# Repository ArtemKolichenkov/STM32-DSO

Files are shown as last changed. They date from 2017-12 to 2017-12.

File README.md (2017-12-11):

# Digital storage oscilloscope using STM32
NOTE! Work in progress, the code has a lot of bugs and should not be used in production.

This project is based on STM32F429ZI microcontroller. Desktop client is written in Python, PCB layout is done in KiCad.
Code will be updated gradually and I will notify when the stable version is released.

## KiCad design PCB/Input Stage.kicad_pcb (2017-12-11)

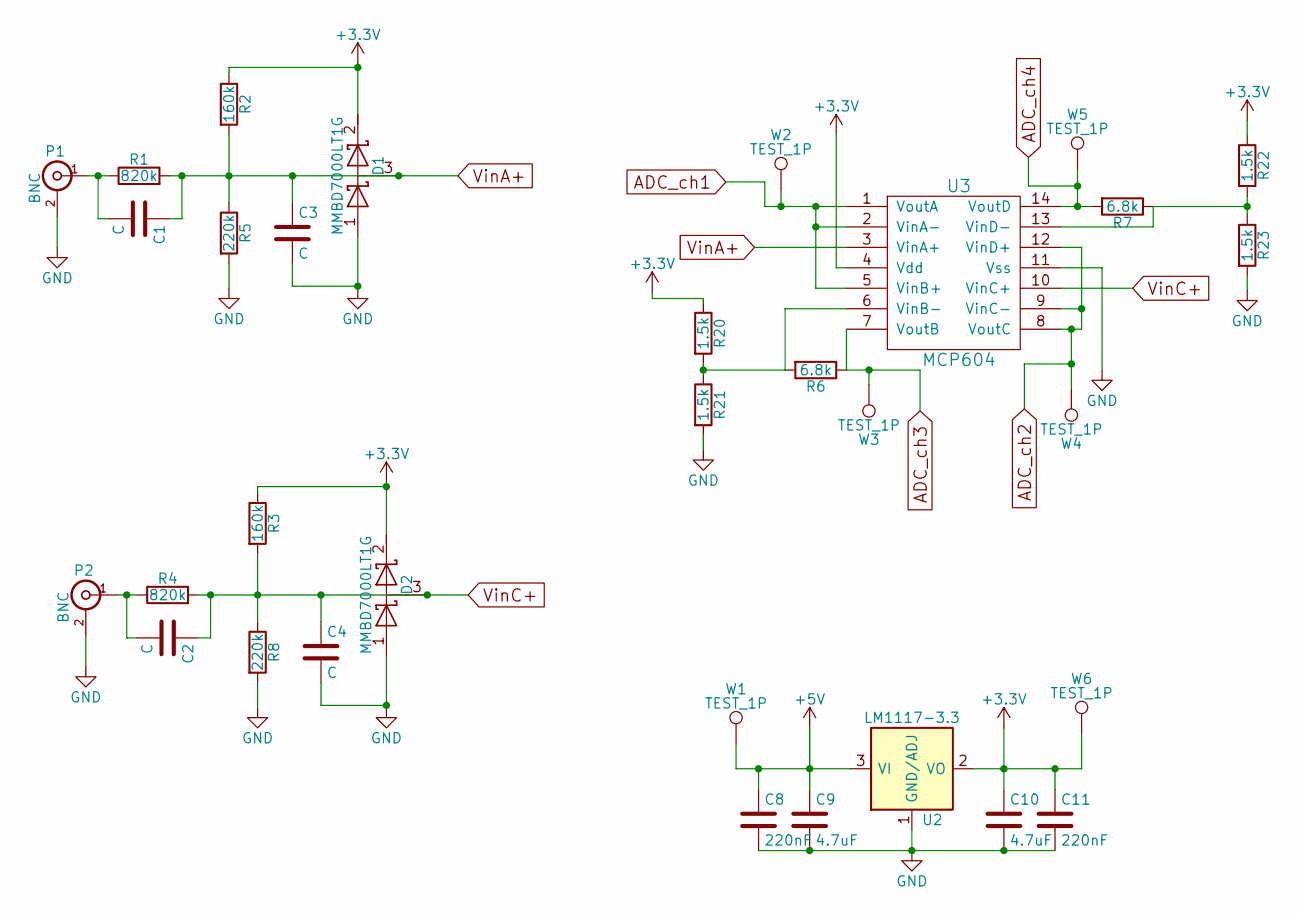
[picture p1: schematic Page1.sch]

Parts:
C1, C2, C3, C4: C; C_0805_HandSoldering
C8, C11: 220nF; C_0805_HandSoldering
C9, C10: 4.7uF; CP_Tantalum_Case-A_EIA-3216-18_Hand
D1, D2: MMBD7000LT1G; SOT-23
P1, P2: BNC; BNC_Socket_TYCO-AMP_LargePads
R1, R4: 820k; R_1206_HandSoldering
R2, R3: 160k; R_1206_HandSoldering
R5, R8: 220k; R_1206_HandSoldering
R6, R7: 6.8k; R_1206_HandSoldering
R20, R21, R22, R23: 1.5k; R_1206_HandSoldering
U2: LM1117-3.3; SOT-223
U3: MCP604; SOIC-14_N
W1, W2, W3, W4, W5, W6: TEST_1P; Measurement_Point_Round-SMD-Pad_Big

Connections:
+5V: C8.1, C9.1, U2.3 (VI), W1.1; also elsewhere on the board
ADC_ch1: U3.1 (VoutA), U3.2 (VinA-), U3.5 (VinB+), W2.1; also elsewhere on the board
ADC_ch2: U3.8 (VoutC), U3.9 (VinC-), U3.12 (VinD+), W4.1; also elsewhere on the board
ADC_ch3: R6.1, U3.7 (VoutB), W3.1; also elsewhere on the board
ADC_ch4: R7.2, U3.14 (VoutD), W5.1; also elsewhere on the board
GND: C3.2, C4.2, C8.2, C9.2, C10.2, C11.2, D1.1 (A), D2.1 (A), P1.2 (Ext), P2.2 (Ext), R5.2, R8.2, R21.2, R23.2, U2.1 (GND/ADJ), U3.11 (Vss); also elsewhere on the board
unnamed: C1.2, P1.1 (In), R1.1
unnamed: C2.2, P2.1 (In), R4.1
unnamed: R6.2, R20.2, R21.1, U3.6 (VinB-)
unnamed: R7.1, R22.2, R23.1, U3.13 (VinD-)
VBAT: C10.1, C11.1, D1.2 (K), D2.2 (K), R2.1, R3.1, R20.1, R22.1, U2.2 (VO), U2.4 (VO), U3.4 (Vdd), W6.1; also elsewhere on the board
VinA+: C1.1, C3.1, D1.3 (common), R1.2, R2.2, R5.1, U3.3 (VinA+)
VinC+: C2.1, C4.1, D2.3 (common), R3.2, R4.2, R8.1, U3.10 (VinC+)

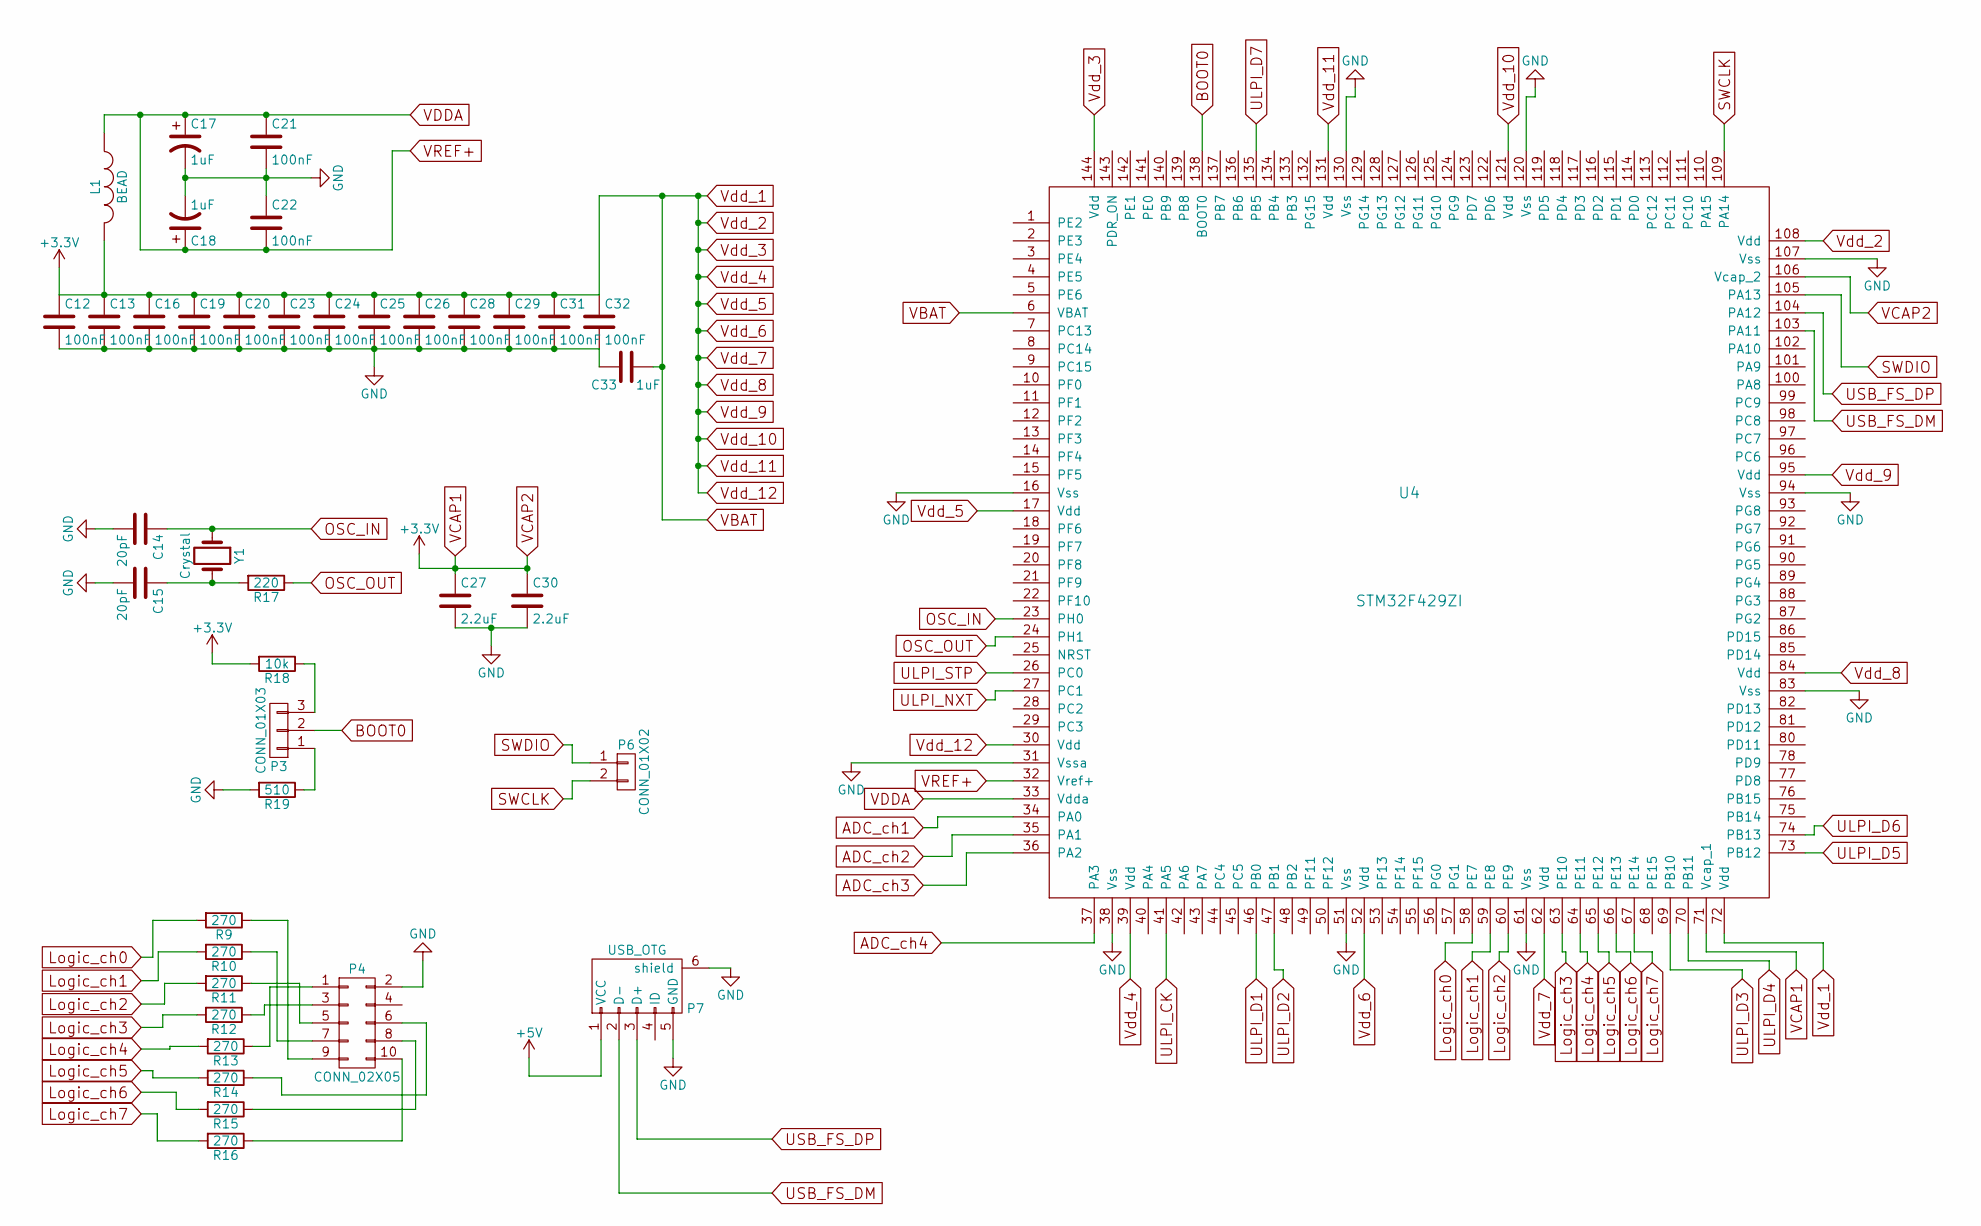
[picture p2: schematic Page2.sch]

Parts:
C12, C13, C16, C19, C20, C21, C22, C23, C24, C25, C26, C28, C29, C31, C32: 100nF; C_0805_HandSoldering
C14, C15: 20pF; C_0805_HandSoldering
C17, C18: 1uF; CP_Tantalum_Case-A_EIA-3216-18_Hand
C27, C30: 2.2uF; C_0805_HandSoldering
C33: 1uF; C_0805_HandSoldering
L1: BEAD; C_1210_HandSoldering
P3: CONN_01X03; Pin_Header_Straight_1x03_Pitch2.54mm
P4: CONN_02X05; IDC_Header_Straight_10pins
P6: CONN_01X02; Pin_Header_Straight_1x02_Pitch2.54mm
P7: USB_OTG; USB_Mini-B
R9, R10, R11, R12, R13, R14, R15, R16: 270; R_1206_HandSoldering
R17: 220; R_1206_HandSoldering
R18: 10k; R_1206_HandSoldering
R19: 510; R_1206_HandSoldering
U4: STM32F429ZI; LQFP-144_20x20mm_Pitch0.5mm
Y1: Crystal; Crystal_SMD_HC49-SD_HandSoldering

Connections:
+5V: P7.1 (VCC); also elsewhere on the board
ADC_ch1: U4.34 (PA0); also elsewhere on the board
ADC_ch2: U4.35 (PA1); also elsewhere on the board
ADC_ch3: U4.36 (PA2); also elsewhere on the board
ADC_ch4: U4.37 (PA3); also elsewhere on the board
BOOT0: P3.2, U4.138 (BOOT0)
GND: C12.2, C13.2, C14.2, C15.2, C16.2, C17.2, C18.2, C19.2, C20.2, C21.2, C22.1, C23.2, C24.2, C25.2, C26.2, C27.2, C28.2, C29.2, C30.2, C31.2, C32.2, C33.2, P4.2, P7.5 (GND), P7.6 (shield), R19.2, U4.16 (Vss), U4.31 (Vssa), U4.38 (Vss), U4.51 (Vss), U4.61 (Vss), U4.83 (Vss), U4.94 (Vss), U4.107 (Vss), U4.120 (Vss), U4.130 (Vss); also elsewhere on the board
Logic_ch0: R9.2, U4.58 (PE7)
Logic_ch1: R10.2, U4.59 (PE8)
Logic_ch2: R11.2, U4.60 (PE9)
Logic_ch3: R12.2, U4.63 (PE10)
Logic_ch4: R13.2, U4.64 (PE11)
Logic_ch5: R14.2, U4.65 (PE12)
Logic_ch6: R15.2, U4.66 (PE13)
Logic_ch7: R16.2, U4.67 (PE14)
unnamed: C15.1, R17.2, Y1.2
unnamed: P3.1, R19.1
unnamed: P3.3, R18.1
unnamed: P4.1, R13.1
unnamed: P4.3, R12.1
unnamed: P4.5, R11.1
unnamed: P4.6, R14.1
unnamed: P4.7, R10.1
unnamed: P4.8, R15.1
unnamed: P4.9, R9.1
unnamed: P4.10, R16.1
OSC_IN: C14.1, U4.23 (PH0), Y1.1
OSC_OUT: R17.1, U4.24 (PH1)
SWCLK: P6.2, U4.109 (PA14)
SWDIO: P6.1, U4.105 (PA13)
ULPI_CK: U4.41 (PA5)
ULPI_D1: U4.46 (PB0)
ULPI_D2: U4.47 (PB1)
ULPI_D3: U4.69 (PB10)
ULPI_D4: U4.70 (PB11)
ULPI_D5: U4.73 (PB12)
ULPI_D6: U4.74 (PB13)
ULPI_D7: U4.135 (PB5)
ULPI_NXT: U4.27 (PC1)
ULPI_STP: U4.26 (PC0)
USB_FS_DM: P7.2 (D-), U4.103 (PA11)
USB_FS_DP: P7.3 (D+), U4.104 (PA12)
VBAT: C12.1, C13.1, C16.1, C19.1, C20.1, C23.1, C24.1, C25.1, C26.1, C27.1, C28.1, C29.1, C30.1, C31.1, C32.1, C33.1, L1.2, R18.2, U4.6 (VBAT), U4.17 (Vdd), U4.30 (Vdd), U4.39 (Vdd), U4.52 (Vdd), U4.62 (Vdd), U4.71 (Vcap_1), U4.72 (Vdd), U4.84 (Vdd), U4.95 (Vdd), U4.106 (Vcap_2), U4.108 (Vdd), U4.121 (Vdd), U4.131 (Vdd), U4.144 (Vdd); also elsewhere on the board
VDDA: C17.1, C18.1, C21.1, C22.2, L1.1, U4.32 (Vref+), U4.33 (Vdda)

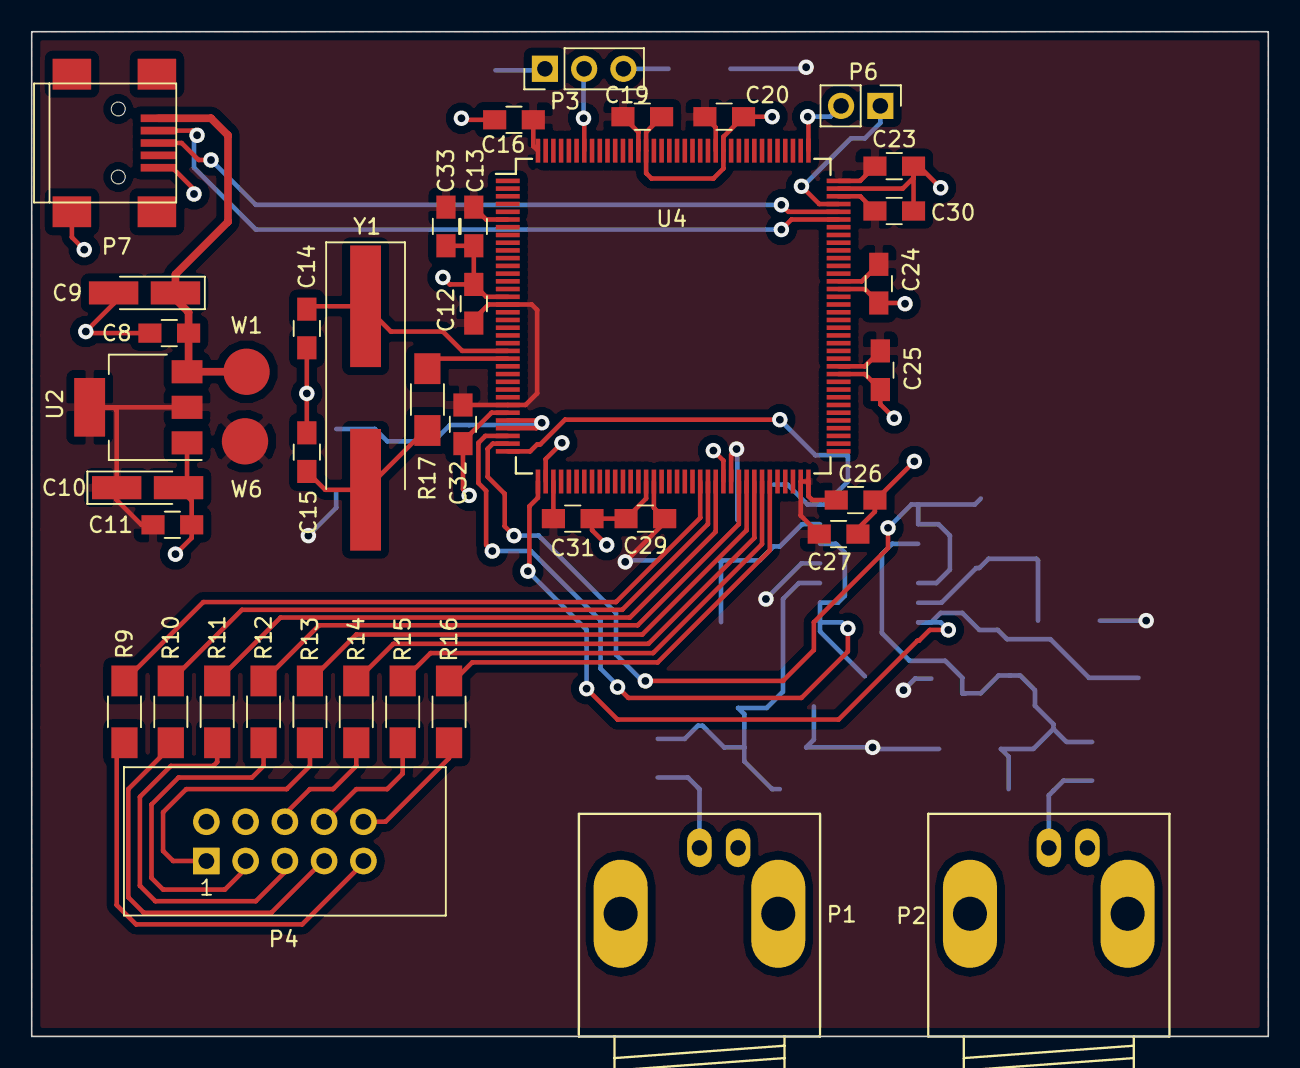
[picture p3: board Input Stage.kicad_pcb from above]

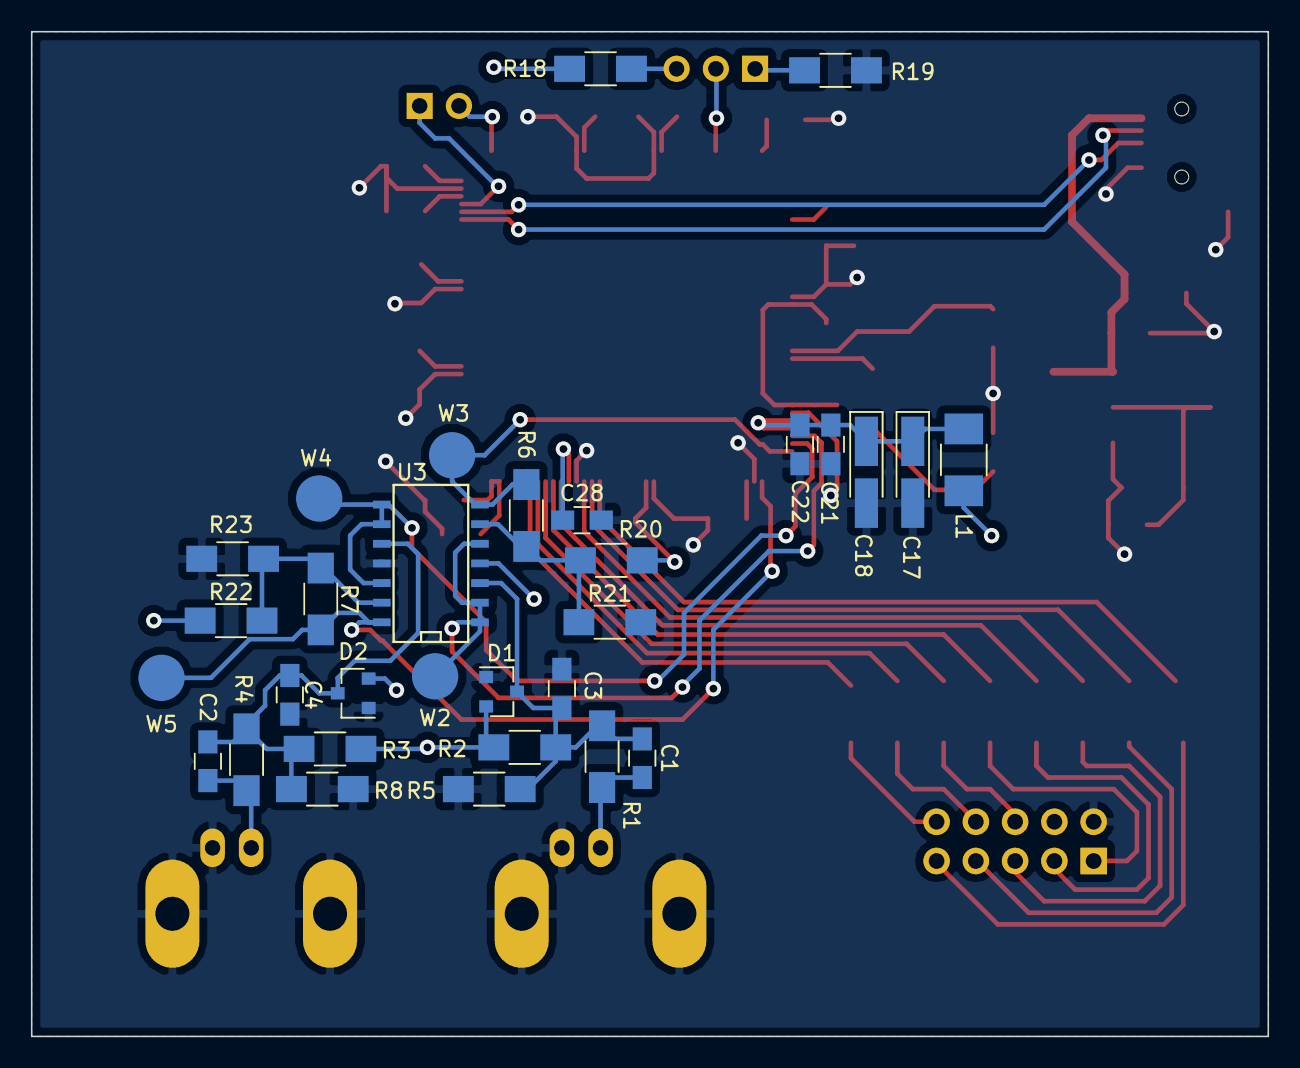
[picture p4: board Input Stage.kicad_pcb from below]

Board: 2 copper layers, 80.0 x 65.0 mm, 72 parts (31 on the bottom side), 40 nets.

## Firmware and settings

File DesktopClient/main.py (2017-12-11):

"""
    Oscilloscope project
"""
from __future__ import division
from PyQt4 import QtGui, QtCore
import design
import sys
import re
import pyqtgraph as pg
import numpy as np
import settings
import serial   
from scipy.signal import blackmanharris
from parabolic import parabolic
import cPickle as pickle

# Initializing configuration object
config = settings.Config()
# Initializing Channel objects for 1st and 2nd channel and setting default parameters
channel_1 = settings.Channel(is_on=True, color='y')
channel_2 = settings.Channel(is_on=False, color='r')

# Initializing Logic objects for logic channels and setting default parameters
logic_channel_0 = settings.LogicChannel(
    is_on=True, color=(255, 255, 255), y_offset=-3.98)
logic_channel_1 = settings.LogicChannel(
    is_on=True, color=(255, 255, 0), y_offset=-3.6)
logic_channel_2 = settings.LogicChannel(
    is_on=True, color=(0, 255, 0), y_offset=-3.22)
logic_channel_3 = settings.LogicChannel(
    is_on=True, color=(0, 0, 255), y_offset=-2.84)
logic_channel_4 = settings.LogicChannel(
    is_on=True, color=(255, 0, 255), y_offset=-2.46)
logic_channel_5 = settings.LogicChannel(
    is_on=True, color=(255, 0, 0), y_offset=-2.08)
logic_channel_6 = settings.LogicChannel(
    is_on=True, color=(0, 255, 255), y_offset=-1.7)
logic_channel_7 = settings.LogicChannel(
    is_on=True, color=(255, 165, 0), y_offset=-1.32)

# Putting logic channels into a list for better code management
logic_channels = [logic_channel_0, logic_channel_1, logic_channel_2, logic_channel_3,
                  logic_channel_4, logic_channel_5, logic_channel_6, logic_channel_7]


def freq_from_fft(channel, fs):
    """
    Estimate frequency from peak of FFT.

    Parameters
    ----------
    channel : Channel object
        Channel to be processed
    fs : int
        Sampling rate

    """
    # Compute Fourier transform of windowed signal
    windowed = channel.signal * blackmanharris(len(channel.signal))
    f = np.fft.rfft(windowed)
    channel.fft_y = np.abs(f)  # amplitude spectrum
    channel.fft_x = np.fft.rfftfreq(channel.signal.size, 1 / fs)
    # Find the peak and interpolate to get a more accurate peak
    i = np.argmax(abs(f))
    true_i = parabolic(np.log(abs(f)), i)[0]

    # Convert to equivalent frequency
    return fs * true_i / len(windowed)


""" Oscilloscope screen related functions are below """


def show_fft_dialog():
    """
    Shows dialog box for FFT and sets curve inside of it.
    """
    fft_dialog = FFTDialog()
    fft_curve = fft_dialog.fft_plot.getPlotItem()
    vb = fft_curve.vb
    fft_curve.plot(channel_1.fft_x[:505], channel_1.fft_y[:505] / 10, pen='w')
    vLine = pg.InfiniteLine(angle=90, movable=False)
    hLine = pg.InfiniteLine(angle=0, movable=False)
    fft_curve.addItem(vLine, ignoreBounds=True)
    fft_curve.addItem(hLine, ignoreBounds=True)
    bottom_axis = fft_curve.getAxis('bottom')
    bottom_axis.setTicks([
        [(1000, '1 kHz'), (50000, '50 kHz'), (100000, '100 kHz'), (200000, '200 kHz'),
         (300000, '300 kHz'), (400000, '400 kHz'), (500000, '500 kHz'), (600000, '600 kHz'),
         (700000, '700 kHz'), (800000, '800 kHz'), (900000, '900 kHz'), (1000000, '1 MHZ')
         ],
        []])
    vb.setLimits(yMin=-20, yMax=400)
    vb.setLimits(xMin=-20000, xMax=1070000)
    label = fft_dialog.freq_label

    def mouseMoved(evt):
        pos = evt[0]  # using signal proxy turns original arguments into a tuple
        if fft_curve.sceneBoundingRect().contains(pos):
            mousePoint = vb.mapSceneToView(pos)
            frequency = int(mousePoint.x())
            if frequency > 1000000:
                frequency = frequency / 1000000
                label.setText("f=%.3F MHz" % frequency)
            elif frequency > 10000:
                frequency = frequency / 1000
                label.setText("f=%.3F kHz" % frequency)
            else:
                label.setText("f=%.3F Hz" % frequency)
            vLine.setPos(mousePoint.x())
            hLine.setPos(mousePoint.y())
    proxy = pg.SignalProxy(fft_curve.scene().sigMouseMoved, rateLimit=60, slot=mouseMoved)
    fft_dialog.exec_()


def plot_fft():
    fft_curve = form.the_plot.plot(pen='w')
    fft_curve.setPos(0, -3.9)
    fft_curve.setData(np.array(range(0, len(channel_1.fft_x)))
                      * (1000 / 1800), channel_1.fft_y / 350)


def acquire_signal(channel):
    """
    Captures data for corresponding channel and makes simple measurements.

    Parameters
    ----------
    channel : Channel object
        Channel where data will be saved.
    """
    def make_measurements(channel, sample_rate):
        channel.max_v = channel.signal.max()
        channel.rms = np.sqrt(np.mean(channel.signal ** 2))
        channel.ptp = np.ptp(channel.signal)
        channel.freq = freq_from_fft(channel, sample_rate)

    if config.original_timescale['value'] <= 0.00005:
        sample_rate = settings.SAMPLE_RATES[0.00005]
    else:
        sample_rate = settings.SAMPLE_RATES[config.original_timescale['value']]

    stm32 = serial.Serial('COM3', 115200) # Baud rate does not matter here since it is not real com port but USB
    stm32.close()
    stm32.open()
    signal_array = np.zeros(7200)
    incoming_data = stm32.read(size=7200)
    for i, x in enumerate(incoming_data):
        # converting 8bit values back to voltages (assuming stable 3.3v supply)
        signal_array[i] = ord(x) * 0.012890625 - 1.65
    
    channel.signal = signal_array

    make_measurements(channel, sample_rate)


def acquire_logic():
    """
    Acquires logic channels data.
    """
    for channel in logic_channels:
        if channel.is_on:
            stm32 = serial.Serial('COM3', 115200) # Baud rate does not matter here since it is not real com port but USB
            stm32.close()
            stm32.open()
            signal_array = np.zeros(1800)
            incoming_data = stm32.read(size=1800)
            for i, x in enumerate(incoming_data):
                signal_array[i] = ord(x)
            channel.signal = signal_array


def plot_logic():
    """
    Plots logic channels onto display.
    """
    def plot_logic_channel(channel):
        channel.curve = form.the_plot.plot(pen=channel.color)
        if config.original_timescale['value'] < 0.00005:
            channel.curve.setPos(
                -((1000 * (0.00005 / config.original_timescale['value']) / 2) - 500), channel.y_offset)
            channel.curve.setData(np.array(range(0, len(channel.signal)))
                                  * (1000 / (config.sample_points / (0.00005 / config.original_timescale['value']))), channel.signal / 4)
        else:
            channel.curve.setPos(
                0, channel.y_offset)
            channel.curve.setData(np.array(range(0, len(channel.signal)))
                                  * (1000 / config.sample_points), channel.signal / 4)
        channel.original_curve = channel.curve.getData()[0]

    for channel in logic_channels:
        if channel.is_on:
            plot_logic_channel(channel)


def update_screen():
    '''
    Updates the oscilloscope screen with new data.
    '''

    def plot_channel(channel):
        channel.curve = form.the_plot.plot(pen=channel.color)
        if config.original_timescale['value'] < 0.00005:
            channel.curve.setPos(
                -((1000 * (0.00005 / config.original_timescale['value']) / 2) - 500), (config.vertical_bounds[1] / 400) * form.vpos_one_slider.value())
            channel.curve.setData(np.array(range(0, len(channel.signal)))
                                  * (1000 / (config.sample_points / (0.00005 / config.original_timescale['value']))), channel.signal)
        else:
            channel.curve.setPos(
                0, (config.vertical_bounds[1] / 400) * form.vpos_one_slider.value())
            channel.curve.setData(np.array(range(0, len(channel.signal)))
                                  * (1000 / config.sample_points), channel.signal)
        channel.original_curve = channel.curve.getData()[0]

    stm32 = serial.Serial('COM3', 115200) # Baud rate does not matter here since it is not real com port but USB
    stm32.close()
    stm32.open()

    if channel_1.is_on and channel_2.is_on:
        stm32.write(b'110')
        acquire_signal(channel_1)
        acquire_signal(channel_2)
        plot_channel(channel_1)
        plot_channel(channel_2)
        vertical_position_changed(channel_1, form.vpos_one_slider, form.vpos_one_value_label)
        vertical_position_changed(channel_2, form.vpos_two_slider, form.vpos_two_value_label)
    elif channel_1.is_on:
        stm32.write(b'100')
        acquire_signal(channel_1)
        plot_channel(channel_1)
        update_measurements()
        vertical_position_changed(channel_1, form.vpos_one_slider, form.vpos_one_value_label)
    else:
        stm32.write(b'010')
        acquire_signal(channel_2)
        plot_channel(channel_2)
        vertical_position_changed(channel_2, form.vpos_two_slider, form.vpos_two_value_label)

    if config.logic_on:
        stm32.write(b'001')
        acquire_logic()
        plot_logic()


def move_horizontal(self):
    '''
    Moves the oscilloscope screen when interacting with horizontal scrollbar.
    '''
    form.the_plot.setXRange(0 + self * 100, 1000 + self * 100, padding=0)


def logic_onoff(logic):
    """
    Turns on logic channels and changes display accordingly.

    Parameters
    ----------
    logic : boolean
        State of logic channels (on/off). Set automatically from GUI event.
    """
    config.logic_on = logic
    if not logic:
        clear_logic_screen()
        form.logic_button.setText("Logic OFF")
    if logic:
        plot_logic()
        form.logic_button.setText("Logic ON")
    check_if_all_channels_off()


def clear_logic_screen():
    """
    Removes logic channels curves from the display.
    """
    for channel in logic_channels:
        form.the_plot.removeItem(channel.curve)


def logic_channel_onoff(checkbox, channel):
    """
    Disables/Enables logic channel.
    Parameters
    ----------
    checkbox : QCheckBox object
        The checkbox that was changed
    channel : LogicChannel object
        LogicChannel instance for corresponding channel

    """
    channel.is_on = checkbox.isChecked()


""" Buttons events for Functions menu are below """


def single():
    '''
    Takes a single snapshot of a signal.
    The length of snapshot is the sample window currently used (or several windows if it is less than 1000 points).
    '''

    clear_screen()
    update_screen()


def clear_screen():
    '''
    Clears oscilloscope screen and erases the data stored in Channel.curve.
    '''
    form.the_plot.removeItem(channel_1.curve)
    channel_1.curve = None

    form.the_plot.removeItem(channel_2.curve)
    channel_2.curve = None

    clear_logic_screen()
    for channel in logic_channels:
        channel.curve = None
        channel.signal = np.array([])


""" Channel controll GUI functions are below """


def ch1_on_off(self):
    """
    Turns on channel_1 object and updates GUI.
    Parameters
    ----------
    self : boolean
        ON/OFF state of channel. Set up automatically from GUI event.
    """
    if self:
        channel_1.is_on = True
        update_GUI()
    else:
        channel_1.is_on = False
        update_GUI()

    check_if_all_channels_off()


def ch2_on_off(self):
    """
    Turns on channel_2 object and updates GUI.

    Parameters
    ----------
    self : boolean
        ON/OFF state of channel. Set up automatically from GUI event.
    """
    if self:
        channel_2.is_on = True
        update_GUI()
    else:
        channel_2.is_on = False
        update_GUI()

    check_if_all_channels_off()


def check_if_all_channels_off():
    """
    Checks if all channels turned off and updates GUI accordingly.
    """
    if not channel_1.is_on and not channel_2.is_on and not config.logic_on:
        form.single_button.setEnabled(False)
        form.run_button.setEnabled(False)
    else:
        form.single_button.setEnabled(True)
        form.run_button.setEnabled(True)


def time_resolution_changed(self):
    """
    Zooms in and out when time resolution changed
    """
    def plot_resized_channel(channel, multiplier):
        if config.original_timescale['value'] < 0.00005:
            channel.curve.setPos(-((1000 * (0.00005 /
                                            config.original_timescale['value']) * multiplier / 2) - 500), 0)
        else:
            channel.curve.setPos(500 - ((1000 * multiplier) / 2), 0)
        channel.curve.setData(channel.original_curve * multiplier, channel.curve.getData()[1])

    def plot_resized_logic_channel(channel, multiplier):
        if config.original_timescale['value'] < 0.00005:
            channel.curve.setPos(-((1000 * (0.00005 /
                                            config.original_timescale['value']) * multiplier / 2) - 500), 0)
        else:
            channel.curve.setPos(500 - ((1000 * multiplier) / 2), channel.y_offset)
        channel.curve.setData(channel.original_curve * multiplier, channel.curve.getData()[1])

    config.current_timescale['value'] = form.hscale_select.itemData(
        form.hscale_select.currentIndex()).toPyObject()

    # Displaying the Max Frequency value
    update_GUI()

    # Determining multiplier for zooming in and out at signal
    multiplier = config.original_timescale['value'] / config.current_timescale['value']

    # Initialize the new curve array with zoomed in and out values
    if channel_1.curve and channel_2.curve:
        plot_resized_channel(channel_1, multiplier)
        plot_resized_channel(channel_2, multiplier)
    elif channel_1.curve:
        plot_resized_channel(channel_1, multiplier)
    elif channel_2.curve:
        plot_resized_channel(channel_2, multiplier)
    else:
        pass
    vertical_position_changed(channel_1, form.vpos_one_slider, form.vpos_one_value_label)
    vertical_position_changed(channel_2, form.vpos_two_slider, form.vpos_two_value_label)

    if config.logic_on:
        for channel in logic_channels:
            plot_resized_logic_channel(channel, multiplier)


def voltage_changed(channel, new_scale):
    """
    Zooms in and out when voltage resolution changed

    Parameters
    ----------
    channel : Channel object
        Corresponding channel for which the vertical resolution has changed.
    new_scale : QComboBox object
        Combobox from which the new value is taken
    """
    def plot_resized_channel(multiplier):
        channel.curve.setData(channel.curve.getData()[0], channel.signal * multiplier)

    channel.voltage_scale = int(re.search(r'\d+', str(new_scale.currentText())).group(0))
    is_mv = re.search(r'mV', str(new_scale.currentText()))
    if is_mv:
        voltage_multiplier = 1 / (channel.voltage_scale / 1000)
        channel.voltage_mv = True
    else:
        voltage_multiplier = 1 / channel.voltage_scale
        channel.voltage_mv = False
    if channel.curve:
        plot_resized_channel(voltage_multiplier)
    trigger_position_changed(form.trigger_level_slider.value())


def vertical_position_changed(channel, slider, label):
    """
    Moves signal curve up and down according to slider position.

    Parameters
    ----------
    channel : Channel object
        Corresponding channel for which the vertical position has changed.
    slider : QSlider object
        Slider from which the new value is taken
    label: QLabel object
        Label below the slider (to update text readout)
    """
    if channel.curve:
        channel.curve.setPos(channel.curve.pos()[
            0], (config.vertical_bounds[1] / 400) * slider.value())
    label.setText(
        str((config.vertical_bounds[1] / (config.vertical_bounds[1] * 100)) * slider.value()) + " div")


def vertical_zero(channel_number):
    """
    Centers signal vertically.

    Parameters
    ----------
    channel_number : int
        Channel (number 1 or 2) which needs to be centered vertically.
    """
    if channel_number == 1:
        form.vpos_one_slider.setValue(0)
    else:
        form.vpos_two_slider.setValue(0)


""" Trigger related functions are below """


def holdoff_value_changed(self):
    """
    Changes holdoff value and updates GUI.

    Parameters
    ----------
    self : int
        The time value. Set up automatically from GUI event.
    """
    if config.holdoff_suffix == "ns":
        config.holdoff_time = self
        if config.holdoff_time == 1000:
            config.holdoff_time = 1
            config.holdoff_suffix = "us"
            form.holdoff_spinBox.setSuffix("us")
            form.holdoff_spinBox.setValue(1.0)
    elif config.holdoff_suffix == "us":
        config.holdoff_time = self
        if self < 1:
            config.holdoff_time = 999.9
            config.holdoff_suffix = "ns"
            form.holdoff_spinBox.setValue(999.9)
            form.holdoff_spinBox.setSuffix("ns")
        if config.holdoff_time == 1000.0:
            config.holdoff_time = 1
            config.holdoff_suffix = "ms"
            form.holdoff_spinBox.setSuffix("ms")
            form.holdoff_spinBox.setValue(1.0)
    elif config.holdoff_suffix == "ms":
        config.holdoff_time = self
        if self < 1:
            config.holdoff_time = 999.9
            config.holdoff_suffix = "us"
            form.holdoff_spinBox.setValue(999.9)
            form.holdoff_spinBox.setSuffix("us")


def trigger_show(show):
    """
    Shows/hides trigger line on the display.

    Parameters
    ----------
    show : boolean
        Enable/Disable trigger display. Set up automatically from GUI event.
    """
    if show:
        form.show_button.setText('Hide')
        config.trigger_curve = form.the_plot.plot(
            [8, 10000], [form.trigger_level_slider.value() / 100, form.trigger_level_slider.value() / 100], pen=settings.TRIGGER_PEN,  symbolBrush=(119, 172, 48), symbolPen='w', symbol='t2', symbolSize=14)
    else:
        form.show_button.setText('Show')
        form.the_plot.removeItem(config.trigger_curve)
        config.trigger_curve = None


def toggle_trigger_channel(self):
    """
    Selects trigger channel (1 or 2).
    """
    if form.trigger_source_ch1.isChecked():
        config.trigger_source = 1
    else:
        config.trigger_source = 2
    trigger_position_changed(form.trigger_level_slider.value())


def trigger_position_changed(level):
    """
    Sets up new trigger value and updates GUI (trigger line).

    Parameters
    ----------
    level : int
        Enable/Disable trigger display. Set up automatically from GUI event.
    """
    config.trigger_level = level
    if config.trigger_curve:
        config.trigger_curve.setData([8, 10000], [level / 100, level / 100])
    if config.trigger_source == 1:
        voltage_level = config.trigger_level * (channel_1.voltage_scale * 0.01)
        mv_adjust = channel_1.voltage_mv
    else:
        voltage_level = config.trigger_level * (channel_2.voltage_scale * 0.01)
        mv_adjust = channel_2.voltage_mv
    if mv_adjust:
        if abs(voltage_level) > 1000:
            form.trigger_level_value_label.setGeometry(QtCore.QRect(14, 160, 53, 13))
        if abs(voltage_level) < 100:
            form.trigger_level_value_label.setGeometry(QtCore.QRect(22, 160, 47, 13))
        else:
            form.trigger_level_value_label.setGeometry(QtCore.QRect(17, 160, 47, 13))
        form.trigger_level_value_label.setText(str(voltage_level) + "mV")
    else:
        form.trigger_level_value_label.setGeometry(QtCore.QRect(29, 160, 35, 13))
        form.trigger_level_value_label.setText(str(voltage_level) + "V")


def update_measurements():
    """
    Updates GUI for measurements section.
    """
    form.readout_one.setText("CH1_Vpp: " + "%.3f V" % channel_1.ptp)
    form.readout_two.setText("CH1_Freq: " + "%.3f Hz" % channel_1.freq)
    form.readout_three.setText("CH1_Vrms: " + "%.3f V" % channel_1.rms)
    form.readout_four.setText("CH1_Vmax: " + "%.3f V" % channel_1.max_v)
    form.readout_eight.setText("CH2_Vmax: " + "%.3f V" % channel_2.max_v)
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

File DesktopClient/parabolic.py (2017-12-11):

# -*- coding: utf-8 -*-

from __future__ import division
from numpy import polyfit, arange


def parabolic(f, x):
    """Quadratic interpolation for estimating the true position of an
    inter-sample maximum when nearby samples are known.

    f is a vector and x is an index for that vector.

    Returns (vx, vy), the coordinates of the vertex of a parabola that goes
    through point x and its two neighbors.

    Example:
    Defining a vector f with a local maximum at index 3 (= 6), find local
    maximum if points 2, 3, and 4 actually defined a parabola.

    In [3]: f = [2, 3, 1, 6, 4, 2, 3, 1]

    In [4]: parabolic(f, argmax(f))
    Out[4]: (3.2142857142857144, 6.1607142857142856)

    """
    xv = 1 / 2. * (f[x - 1] - f[x + 1]) / (f[x - 1] - 2 * f[x] + f[x + 1]) + x
    yv = f[x] - 1 / 4. * (f[x - 1] - f[x + 1]) * (xv - x)
    return (xv, yv)


def parabolic_polyfit(f, x, n):
    """Use the built-in polyfit() function to find the peak of a parabola

    f is a vector and x is an index for that vector.

    n is the number of samples of the curve used to fit the parabola.
    """
    a, b, c = polyfit(arange(x - n // 2, x + n // 2 + 1), f[x - n // 2:x + n // 2 + 1], 2)
    xv = -0.5 * b / a
    yv = a * xv**2 + b * xv + c
    return (xv, yv)


if __name__ == "__main__":
    from numpy import argmax
    import matplotlib.pyplot as plt

    y = [2, 1, 4, 8, 11, 10, 7, 3, 1, 1]

    xm, ym = argmax(y), y[argmax(y)]
    xp, yp = parabolic(y, argmax(y))

    plot = plt.plot(y)
    plt.hold(True)
    plt.plot(xm, ym, 'o', color='silver')
    plt.plot(xp, yp, 'o', color='blue')
    plt.title('silver = max, blue = estimated max')

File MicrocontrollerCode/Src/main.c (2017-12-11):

#include "main.h"
#include "stm32f4xx_hal.h"
#include "usb_device.h"
#include "usbd_cdc_if.h"

#define ADC_BUFFER_LENGTH_TRIPLE 9999
#define ADC_BUFFER_LENGTH_SINGLE 5555
#define CH1_ENABLED 1
#define CH2_ENABLED 1
#define LOGIC_ENABLED 1
#define CH1_DISABLED 0
#define CH2_DISABLED 0
#define LOGIC_DISABLED 0

// ADC and DMA structures declaration
ADC_HandleTypeDef hadc1;
ADC_HandleTypeDef hadc2;
ADC_HandleTypeDef hadc3;
DMA_HandleTypeDef hdma_adc1;

uint8_t rxdata[3] = {0, 0, 0};
uint8_t ADCBufferTriple[ADC_BUFFER_LENGTH_TRIPLE];
uint8_t ADCBufferSingle1[ADC_BUFFER_LENGTH_SINGLE];
uint8_t ADCBufferSingle2[ADC_BUFFER_LENGTH_SINGLE];
uint8_t LogicBuffer[14400];

void SystemClock_Config(void);
void Error_Handler(void);
static void MX_GPIO_Init(void);
static void MX_DMA_Init(void);
static void TripleADC_Init(void);

void HAL_ADC_ConvCpltCallback(ADC_HandleTypeDef* AdcHandle)
{
	if (AdcHandle == &hadc1)
	{
		CDC_Transmit_FS(ADCBufferSingle1, ADC_BUFFER_LENGTH_SINGLE);
	}
	else {
		CDC_Transmit_FS(ADCBufferSingle2, ADC_BUFFER_LENGTH_SINGLE);
	}
}

void ADC_MultiModeDMAConvCplt(DMA_HandleTypeDef *hdma)
{
	ADC_MultiModeTypeDef multimode;
	
	HAL_ADCEx_MultiModeStop_DMA(&hadc1);
	HAL_ADC_Stop(&hadc3);	
	HAL_ADC_Stop(&hadc2);
	multimode.Mode = ADC_MODE_INDEPENDENT;
	multimode.DMAAccessMode = ADC_DMAACCESSMODE_DISABLED;
	multimode.TwoSamplingDelay = ADC_TWOSAMPLINGDELAY_5CYCLES;
	if (HAL_ADCEx_MultiModeConfigChannel(&hadc1, &multimode) != HAL_OK)
	{
		Error_Handler();
	}
	
	HAL_Delay(100);
	multimode.Mode = ADC_TRIPLEMODE_INTERL;
	multimode.DMAAccessMode = ADC_DMAACCESSMODE_3;
	multimode.TwoSamplingDelay = ADC_TWOSAMPLINGDELAY_5CYCLES;
	if (HAL_ADCEx_MultiModeConfigChannel(&hadc1, &multimode) != HAL_OK)
	{
		Error_Handler();
	}
	CDC_Transmit_FS(ADCBufferTriple, ADC_BUFFER_LENGTH_TRIPLE);
}

void ACQUIRE_CHANNEL_1(void);
void ACQUIRE_CHANNEL_1_TRIPLE(void);
void ACQUIRE_CHANNEL_2(void);
void ACQUIRE_LOGIC(void);

int main(void)
{
	// ADC MultiMode structure for Triple Interleaved mode
	ADC_MultiModeTypeDef multimode;
	
  HAL_Init(); // Initialization of hardware abstraction library
  SystemClock_Config(); // Sytem clocks initialization
  MX_GPIO_Init(); // GPIO initialization
  MX_DMA_Init(); // DMA initialization
  MX_USB_DEVICE_Init(); // USB driver initialization
	TripleADC_Init(); // ADC initialization
	HAL_Delay(250); // Delay for initialization to propagate safely
	
  while (1)
  {
		if (rxdata[0] == CH1_ENABLED)
		{
			if (rxdata[1] == CH2_ENABLED)
			{
				if (rxdata[2] == LOGIC_ENABLED)
				{
					ACQUIRE_CHANNEL_1();
					ACQUIRE_CHANNEL_2();
					ACQUIRE_LOGIC();
				}
				ACQUIRE_CHANNEL_1();
				ACQUIRE_CHANNEL_2();
			}
			else if (rxdata[2] == LOGIC_ENABLED)
			{
				ACQUIRE_CHANNEL_1();
				ACQUIRE_LOGIC();
			}
			ACQUIRE_CHANNEL_1_TRIPLE();
		}
		else if (rxdata[0] == CH1_DISABLED && rxdata[1] == CH2_ENABLED)
		{
			if (rxdata[2] == LOGIC_ENABLED)
			{
				ACQUIRE_CHANNEL_2();
				ACQUIRE_LOGIC();
			}
			ACQUIRE_CHANNEL_2();
		}
		else if (rxdata[0] == CH1_DISABLED && rxdata[1] == CH2_DISABLED && rxdata[2] == LOGIC_ENABLED)
		{
			ACQUIRE_LOGIC();
		}		
  }
}

void ACQUIRE_CHANNEL_1(void) 
{
	HAL_ADC_Start_DMA(&hadc1, (uint32_t*) ADCBufferSingle1, ADC_BUFFER_LENGTH_SINGLE);
}

void ACQUIRE_CHANNEL_2(void) 
{
	HAL_ADC_Start_DMA(&hadc2, (uint32_t*) ADCBufferSingle2, ADC_BUFFER_LENGTH_SINGLE);
}

void ACQUIRE_CHANNEL_1_TRIPLE(void) 
{	
	HAL_ADC_Start(&hadc3);
	HAL_ADC_Start(&hadc2);
	HAL_ADCEx_MultiModeStart_DMA(&hadc1, (uint32_t*) &ADCBufferTriple, ADC_BUFFER_LENGTH_TRIPLE);
}

void ACQUIRE_LOGIC(void) 
{
	for (uint32_t i = 0; i < 14400; i++)
	{
		LogicBuffer[i+i*7] = HAL_GPIO_ReadPin(GPIOE, GPIO_PIN_7);
		LogicBuffer[i+i*7+1] = HAL_GPIO_ReadPin(GPIOE, GPIO_PIN_8);
		LogicBuffer[i+i*7+2] = HAL_GPIO_ReadPin(GPIOE, GPIO_PIN_9);
		LogicBuffer[i+i*7+3] = HAL_GPIO_ReadPin(GPIOE, GPIO_PIN_10);
		LogicBuffer[i+i*7+4] = HAL_GPIO_ReadPin(GPIOE, GPIO_PIN_11);
		LogicBuffer[i+i*7+5] = HAL_GPIO_ReadPin(GPIOE, GPIO_PIN_12);
		LogicBuffer[i+i*7+6] = HAL_GPIO_ReadPin(GPIOE, GPIO_PIN_13);
		LogicBuffer[i+i*7+7] = HAL_GPIO_ReadPin(GPIOE, GPIO_PIN_14);
	}
	CDC_Transmit_FS(LogicBuffer, 14400);
}

void SystemClock_Config(void)
{

  RCC_OscInitTypeDef RCC_OscInitStruct;
  RCC_ClkInitTypeDef RCC_ClkInitStruct;

    /**Configure the main internal regulator output voltage 
    */
  __HAL_RCC_PWR_CLK_ENABLE();

  __HAL_PWR_VOLTAGESCALING_CONFIG(PWR_REGULATOR_VOLTAGE_SCALE3);

    /**Initializes the CPU, AHB and APB busses clocks 
    */
  RCC_OscInitStruct.OscillatorType = RCC_OSCILLATORTYPE_HSE;
  RCC_OscInitStruct.HSEState = RCC_HSE_ON;
  RCC_OscInitStruct.PLL.PLLState = RCC_PLL_ON;
  RCC_OscInitStruct.PLL.PLLSource = RCC_PLLSOURCE_HSE;
  RCC_OscInitStruct.PLL.PLLM = 4;
  RCC_OscInitStruct.PLL.PLLN = 72;
  RCC_OscInitStruct.PLL.PLLP = RCC_PLLP_DIV2;
  RCC_OscInitStruct.PLL.PLLQ = 3;
  if (HAL_RCC_OscConfig(&RCC_OscInitStruct) != HAL_OK)
  {
    Error_Handler();
  }

    /**Initializes the CPU, AHB and APB busses clocks 
    */
  RCC_ClkInitStruct.ClockType = RCC_CLOCKTYPE_HCLK|RCC_CLOCKTYPE_SYSCLK
                              |RCC_CLOCKTYPE_PCLK1|RCC_CLOCKTYPE_PCLK2;
  RCC_ClkInitStruct.SYSCLKSource = RCC_SYSCLKSOURCE_PLLCLK;
  RCC_ClkInitStruct.AHBCLKDivider = RCC_SYSCLK_DIV1;
  RCC_ClkInitStruct.APB1CLKDivider = RCC_HCLK_DIV2;
  RCC_ClkInitStruct.APB2CLKDivider = RCC_HCLK_DIV1;

  if (HAL_RCC_ClockConfig(&RCC_ClkInitStruct, FLASH_LATENCY_2) != HAL_OK)
  {
    Error_Handler();
  }

    /**Configure the Systick interrupt time 
    */
  HAL_SYSTICK_Config(HAL_RCC_GetHCLKFreq()/1000);

    /**Configure the Systick 
    */
  HAL_SYSTICK_CLKSourceConfig(SYSTICK_CLKSOURCE_HCLK);

  /* SysTick_IRQn interrupt configuration */
  HAL_NVIC_SetPriority(SysTick_IRQn, 0, 0);
}
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
